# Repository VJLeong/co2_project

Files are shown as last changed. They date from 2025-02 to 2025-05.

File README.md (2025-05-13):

#  Automated Compensation of Environmental Changes on CO2 Gas Sensor Response
Project Supervisor: Dr. Ajay Achath Mohanan <br>
Project Members: Leong Van Jun, Vincent Law Yun Kae <br>
Project Commence Date: November 2024 - Present <br>
## Project Description <br>
The main objective of the project is to introduce Artificial Intelligence (AI) and/or machine learning (ML) tools to assist in analysing patterns in obtained carbon dioxide sensor readings and filtering of unwanted noises. <br>
This objective is achieved through proper setting up of the hardware setup and environment of the carbon dioxide sensor. Which is achieved by constructing of appropriate PCB and testing through external microcontroller units. <br>
For this project, the microcontroller unit used is the PSoC 5LP module and PCB design software used is Kicad 8.

## Changelog
### 13/5/2025:
  - Redesigned second version of external chamber PCB --  ready for remanufacturing if needed
  - Updated PID controller for heater controls to P controller (Kp = 120.0f)
### 18/4/2025:
  - Added external chamber PCB schematic design into the repo
  - Begin testing with external chamber PCB prototype
### 23/3/2025:
  - Updated capacitance.py to remove KNN cluster and median filtering algorithm to display raw data output in graph
  - Added heater PID bang-bang control and temperature sensor (3/3 tasks)
### 3/3/2025:
  - Written Python script involving KNN machine learning algorithm to help effeciently filter outlier values in read capacitance values
### 22/2/2025:
  - Re-updated read_capacitance function
  - Included improved analogue circuitry to measure capacitance, now using an
    NE556N timer module instead of simple RC circuit (LTSpice file included!)
### 13/2/2025:
  - Completed two tasks of three: Measure capacitance via PSoC
  - Currently debugging capacitance value, current capacitance value too small!
### 12/2/2025: 
  - Uploaded PSoC Creator and Kicad project files into Github repo for the first time.
  - Completed one task of three: Interface SCD30 on PCB with PSoC 5LP to obtain CO2 concentration, temperature, and relative humidity levels (rh%)

## Reference Materials
SCD30 item website: https://sensirion.com/products/catalog/SCD30 <br>
SCD30 Datasheet: https://sensirion.com/media/documents/4EAF6AF8/61652C3C/Sensirion_CO2_Sensors_SCD30_Datasheet.pdf <br>
SCD30 Interface Description: https://sensirion.com/media/documents/D7CEEF4A/6165372F/Sensirion_CO2_Sensors_SCD30_Interface_Description.pdf <br>
SCD30 Example Code: https://github.com/Sensirion/embedded-scd/releases/tag/2.1.1 <br>

## Acknowledgement
Thank you to Dr. Ajay for his supervision and guidance for the project members throughout the project duration.

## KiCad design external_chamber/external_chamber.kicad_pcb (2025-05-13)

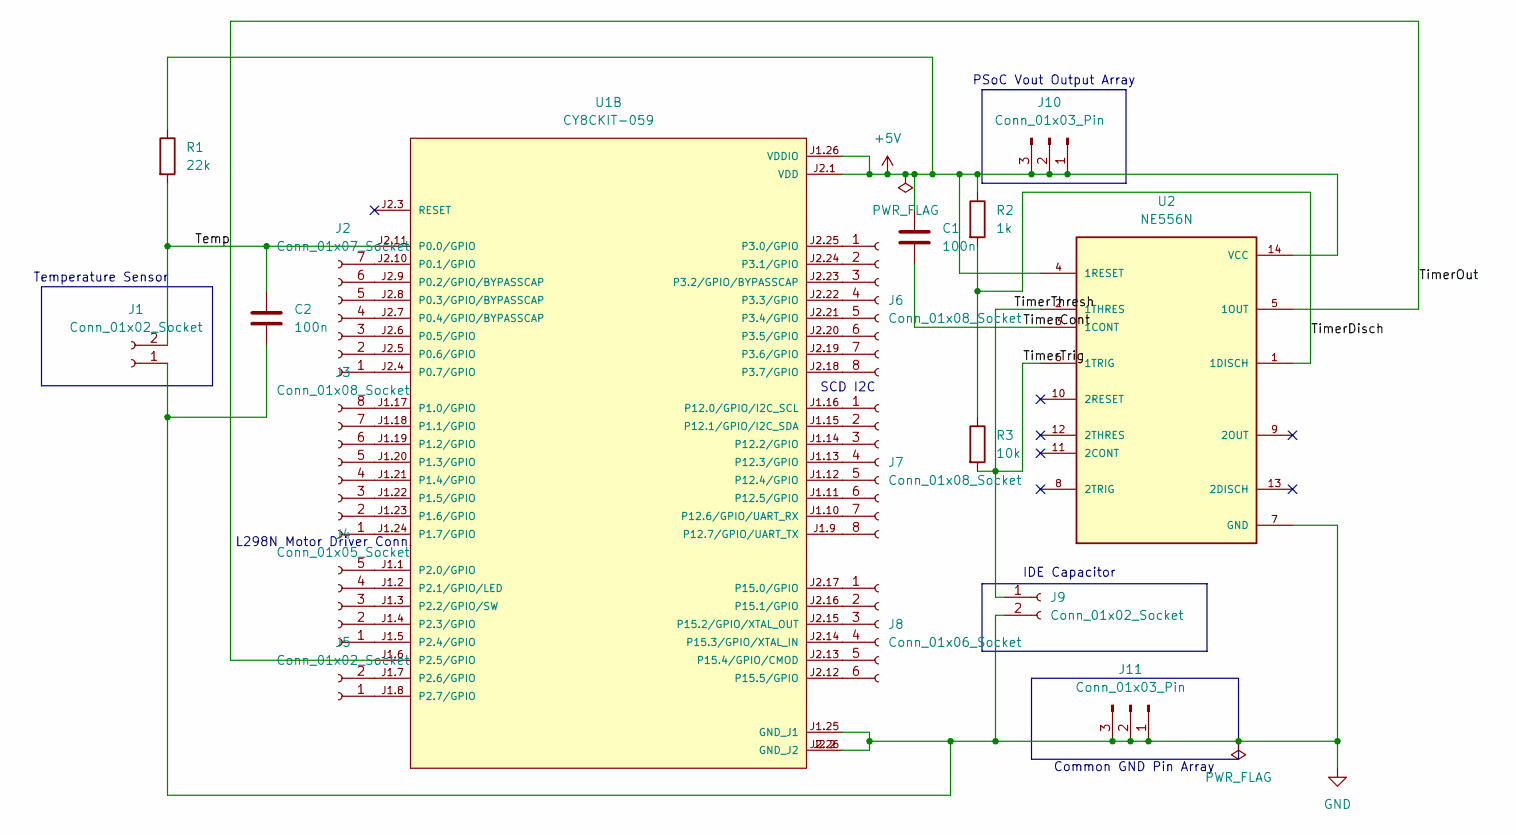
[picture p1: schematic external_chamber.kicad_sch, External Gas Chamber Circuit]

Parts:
C1, C2: 100n; C_Disc_D5.0mm_W2.5mm_P5.00mm
J1: Conn_01x02_Socket; PinHeader_1x02_P2.54mm_Vertical
J2: Conn_01x07_Socket; PinSocket_1x07_P2.54mm_Vertical
J3, J6: Conn_01x08_Socket; PinSocket_1x08_P2.54mm_Vertical
J4: Conn_01x05_Socket; PinSocket_1x05_P2.54mm_Vertical
J5, J9: Conn_01x02_Socket; PinSocket_1x02_P2.54mm_Vertical
J7: Conn_01x08_Socket; PinHeader_1x08_P2.54mm_Vertical
J8: Conn_01x06_Socket; PinSocket_1x06_P2.54mm_Vertical
J10, J11: Conn_01x03_Pin; PinSocket_1x03_P2.54mm_Vertical
R1: 22k; R_Axial_DIN0207_L6.3mm_D2.5mm_P7.62mm_Horizontal
R2: 1k; R_Axial_DIN0207_L6.3mm_D2.5mm_P7.62mm_Horizontal
R3: 10k; R_Axial_DIN0207_L6.3mm_D2.5mm_P7.62mm_Horizontal
U1: CY8CKIT-059; MODULE_CY8CKIT-059; PARTREV G
U2: NE556N; DIP794W45P254L1930H508Q14; PARTREV JUNE 2006; DigiKey_Part_Number 296-6504-5-ND

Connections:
+5V: C1.1, J10.1, J10.2, J10.3, R1.1, R2.1, U1.J1.26 (VDDIO), U1.J2.1 (VDD), U2.4 (1RESET), U2.14 (VCC)
/Temp: C2.1, J1.2, R1.2, U1.J2.11 (P0.0/GPIO)
/TimerCont: C1.2, U2.3 (1CONT)
/TimerDisch: R2.2, R3.1, U2.1 (1DISCH)
/TimerOut: U1.J1.6 (P2.5/GPIO), U2.5 (1OUT)
/TimerThresh: J9.1, R3.2, U2.2 (1THRES), U2.6 (1TRIG)
GND: C2.2, J1.1, J9.2, J11.1, J11.2, J11.3, U1.J1.25 (GND_J1), U1.J2.2 (GND_J2), U1.J2.26 (GND_J2), U2.7 (GND)
unnamed: J2.1, U1.J2.4 (P0.7/GPIO)
unnamed: J2.2, U1.J2.5 (P0.6/GPIO)
unnamed: J2.3, U1.J2.6 (P0.5/GPIO)
unnamed: J2.4, U1.J2.7 (P0.4/GPIO/BYPASSCAP)
unnamed: J2.5, U1.J2.8 (P0.3/GPIO/BYPASSCAP)
unnamed: J2.6, U1.J2.9 (P0.2/GPIO/BYPASSCAP)
unnamed: J2.7, U1.J2.10 (P0.1/GPIO)
unnamed: J3.1, U1.J1.24 (P1.7/GPIO)
unnamed: J3.2, U1.J1.23 (P1.6/GPIO)
unnamed: J3.3, U1.J1.22 (P1.5/GPIO)
unnamed: J3.4, U1.J1.21 (P1.4/GPIO)
unnamed: J3.5, U1.J1.20 (P1.3/GPIO)
unnamed: J3.6, U1.J1.19 (P1.2/GPIO)
unnamed: J3.7, U1.J1.18 (P1.1/GPIO)
unnamed: J3.8, U1.J1.17 (P1.0/GPIO)
unnamed: J4.1, U1.J1.5 (P2.4/GPIO)
unnamed: J4.2, U1.J1.4 (P2.3/GPIO)
unnamed: J4.3, U1.J1.3 (P2.2/GPIO/SW)
unnamed: J4.4, U1.J1.2 (P2.1/GPIO/LED)
unnamed: J4.5, U1.J1.1 (P2.0/GPIO)
unnamed: J5.1, U1.J1.8 (P2.7/GPIO)
unnamed: J5.2, U1.J1.7 (P2.6/GPIO)
unnamed: J6.1, U1.J2.25 (P3.0/GPIO)
unnamed: J6.2, U1.J2.24 (P3.1/GPIO)
unnamed: J6.3, U1.J2.23 (P3.2/GPIO/BYPASSCAP)
unnamed: J6.4, U1.J2.22 (P3.3/GPIO)
unnamed: J6.5, U1.J2.21 (P3.4/GPIO)
unnamed: J6.6, U1.J2.20 (P3.5/GPIO)
unnamed: J6.7, U1.J2.19 (P3.6/GPIO)
unnamed: J6.8, U1.J2.18 (P3.7/GPIO)
unnamed: J7.1, U1.J1.16 (P12.0/GPIO/I2C_SCL)
unnamed: J7.2, U1.J1.15 (P12.1/GPIO/I2C_SDA)
unnamed: J7.3, U1.J1.14 (P12.2/GPIO)
unnamed: J7.4, U1.J1.13 (P12.3/GPIO)
unnamed: J7.5, U1.J1.12 (P12.4/GPIO)
unnamed: J7.6, U1.J1.11 (P12.5/GPIO)
unnamed: J7.7, U1.J1.10 (P12.6/GPIO/UART_RX)
unnamed: J7.8, U1.J1.9 (P12.7/GPIO/UART_TX)
unnamed: J8.1, U1.J2.17 (P15.0/GPIO)
unnamed: J8.2, U1.J2.16 (P15.1/GPIO)
unnamed: J8.3, U1.J2.15 (P15.2/GPIO/XTAL_OUT)
unnamed: J8.4, U1.J2.14 (P15.3/GPIO/XTAL_IN)
unnamed: J8.5, U1.J2.13 (P15.4/GPIO/CMOD)
unnamed: J8.6, U1.J2.12 (P15.5/GPIO)

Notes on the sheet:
SCD I2C
IDE Capacitor
PSoC Vout Output Array
Common GND Pin Array
Temperature Sensor
L298N Motor Driver Conn.

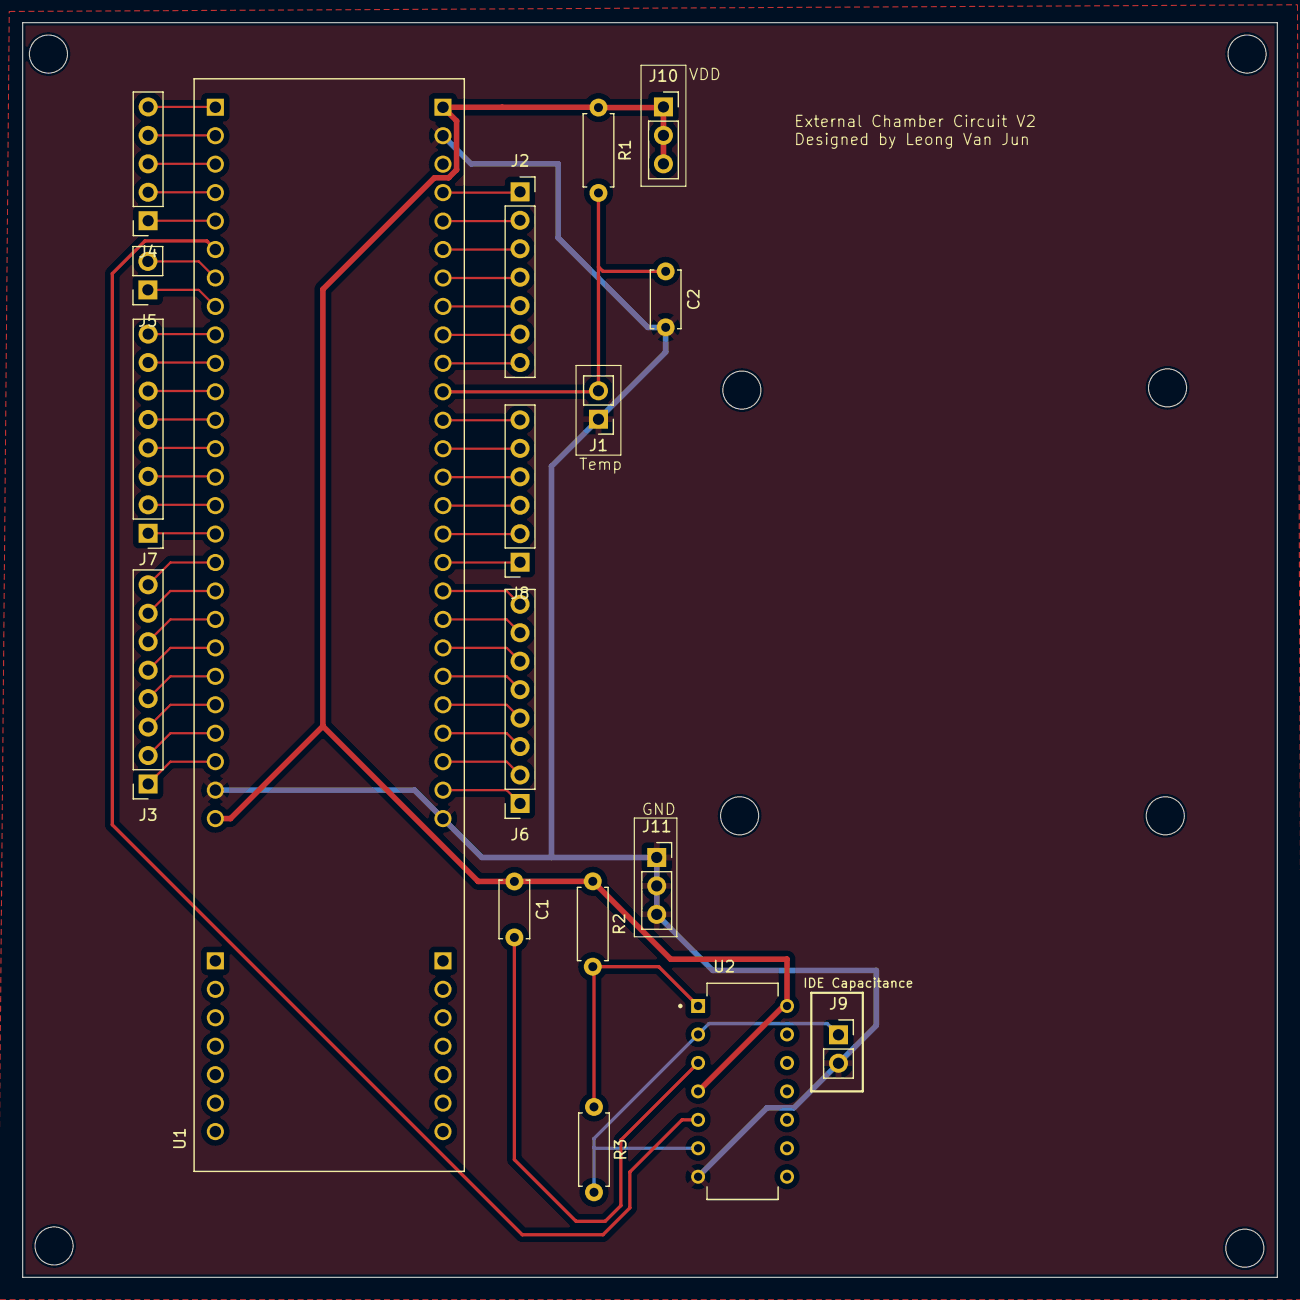
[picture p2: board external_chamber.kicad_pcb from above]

Board: 2 copper layers, 112.0 x 112.0 mm, 18 parts (0 on the bottom side), 51 nets.

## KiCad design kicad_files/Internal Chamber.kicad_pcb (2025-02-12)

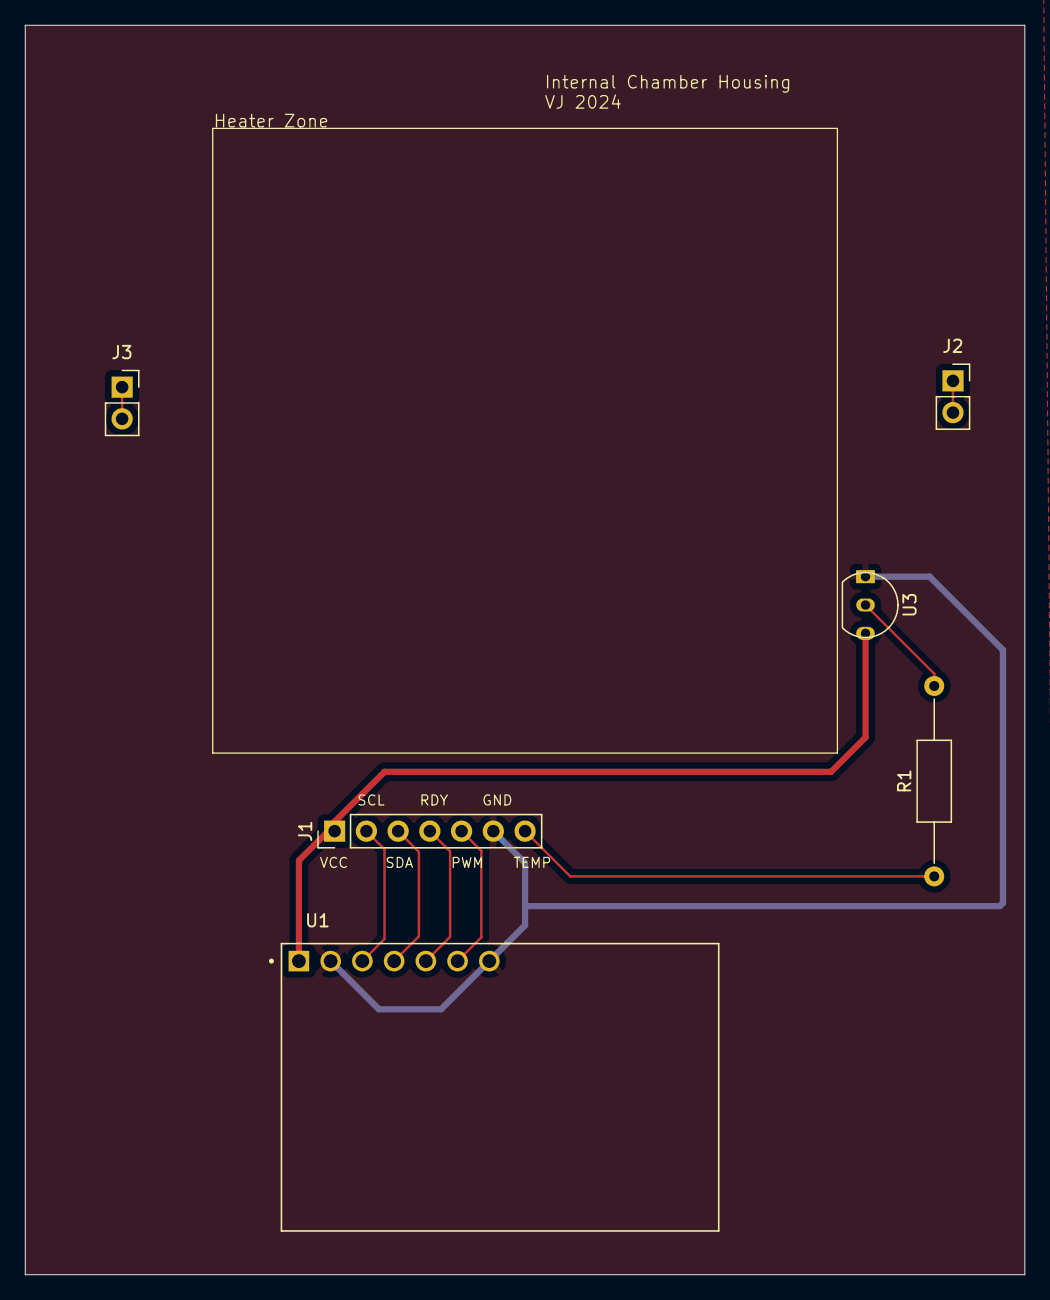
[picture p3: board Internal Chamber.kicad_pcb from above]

Board: 2 copper layers, 80.0 x 100.0 mm, 6 parts (0 on the bottom side), 9 nets.

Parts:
J1: Conn_01x07_Pin; PinHeader_1x07_P2.54mm_Vertical
J2, J3: Conn_01x02_Pin; PinSocket_1x02_P2.54mm_Vertical
R1: 4.7k; R_Axial_DIN0207_L6.3mm_D2.5mm_P15.24mm_Horizontal
U1: SCD30; MODULE_SCD30
U3: DS18B20; TO-92_Inline

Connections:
/Data: J2.1, J2.2, J3.1, J3.2
/PWM: J1.5, U1.6 (PWM)
/RDY: J1.4, U1.5 (RDY)
/SCL: J1.2, U1.3 (TX/SCL)
/SDA: J1.3, U1.4 (RX/SDA)
/TEMP: J1.7, R1.1
/VCC: J1.1, U1.1 (VDD), U3.3 (V_{DD})
GND: J1.6, U1.2 (GND), U1.7 (SEL), U3.1 (GND)
unnamed: R1.2, U3.2 (DQ)

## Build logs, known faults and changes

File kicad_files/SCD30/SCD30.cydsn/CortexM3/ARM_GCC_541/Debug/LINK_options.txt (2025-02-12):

-Wl,--start-group -o "F:\\Downloads\\kicad\\sandbox\\Internal\ Chamber\\SCD30\\SCD30.cydsn\\CortexM3\\ARM_GCC_541\\Debug\\SCD30.elf" ".\\CortexM3\\ARM_GCC_541\\Debug\\main.o" ".\\CortexM3\\ARM_GCC_541\\Debug\\cyfitter_cfg.o" ".\\CortexM3\\ARM_GCC_541\\Debug\\cymetadata.o" ".\\CortexM3\\ARM_GCC_541\\Debug\\Cm3Start.o" ".\\CortexM3\\ARM_GCC_541\\Debug\\SCD30.a" "F:\\PSoC\ Creator\\4.4\\PSoC\ Creator\\psoc\\content\\cycomponentlibrary\\CyComponentLibrary.cylib\\CortexM3\\ARM_GCC_541\\Debug\\CyComponentLibrary.a" -mcpu=cortex-m3 -mthumb -L "Generated_Source\\PSoC5" "-Wl,-Map,.\\CortexM3\\ARM_GCC_541\\Debug/SCD30.map" -T "Generated_Source\\PSoC5\\cm3gcc.ld" -specs=nano.specs -Wl,--gc-sections -u_printf_float -g -ffunction-sections -Og -ffat-lto-objects -Wl,--end-group

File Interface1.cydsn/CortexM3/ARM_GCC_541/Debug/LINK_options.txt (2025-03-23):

-Wl,--start-group -o "F:\\Downloads\\SLED\\Workspace01\\Interface1.cydsn\\CortexM3\\ARM_GCC_541\\Debug\\Interface1.elf" ".\\CortexM3\\ARM_GCC_541\\Debug\\main.o" ".\\CortexM3\\ARM_GCC_541\\Debug\\cyfitter_cfg.o" ".\\CortexM3\\ARM_GCC_541\\Debug\\cymetadata.o" ".\\CortexM3\\ARM_GCC_541\\Debug\\Cm3Start.o" ".\\CortexM3\\ARM_GCC_541\\Debug\\Interface1.a" "F:\\PSoC\ Creator\\4.4\\PSoC\ Creator\\psoc\\content\\cycomponentlibrary\\CyComponentLibrary.cylib\\CortexM3\\ARM_GCC_541\\Debug\\CyComponentLibrary.a" -mcpu=cortex-m3 -mthumb -l m -L "Generated_Source\\PSoC5" "-Wl,-Map,.\\CortexM3\\ARM_GCC_541\\Debug/Interface1.map" -T "Generated_Source\\PSoC5\\cm3gcc.ld" -u _printf_float -Wl,--gc-sections -u_printf_float -g -ffunction-sections -Og -ffat-lto-objects -Wl,--end-group

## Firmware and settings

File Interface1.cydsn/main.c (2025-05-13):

#include "project.h"
#include <stdlib.h>
#include <stdio.h>
#include <math.h>

// Definitions
#define SCD30_I2C_ADDRESS 0x61
#define R1 1000.0 // 1k ohm resistor
#define R2 10000.0 // 10k ohm resistor
#define R3 22000.0 //22k ohm resistor
#define VREF 4.9
#define ADC_MAX_VALUE 4095
// JS6670 nominal parameters (from datasheet/specs)
#define R0          9983.0      // Nominal resistance at 25°C in Ohms
#define T0          298.15      // Nominal temperature in Kelvin (25°C)
#define BETA        3870.0     // Beta parameter in Kelvin

// Function prototypes
void I2C_Write(uint8_t *data, uint8_t length);
void I2C_Read(uint8_t *data, uint8_t length);
void read_sensor_data();
void read_capacitance();
void heater();
void read_temperature();
// Global variables
char string_1[100];
uint8_t buffer[18]; // Buffer for 18 bytes of data
uint16 adcResult;
int heaterDutyCycle;
uint8 status;
float  voltage;
float  R_thermistor;
float  temperatureK, temperatureC;
int    tempCeil;
// Temperature control (PID)
float Kp = 120.0f;
float Ki = 0.0f;
float Kd = 0.0f;
float dt = 0.001f; // Sampling every 1ms
float setpoint = 60.0f;
float error, derivative, integral, prevErr;

void I2C_Write(uint8_t *data, uint8_t length) {
    I2C_1_MasterWriteBuf(SCD30_I2C_ADDRESS, data, length, I2C_1_MODE_COMPLETE_XFER);
    while(I2C_1_MasterStatus() & I2C_1_MSTAT_XFER_INP);
}

void I2C_Read(uint8_t *data, uint8_t length) {
    I2C_1_MasterReadBuf(SCD30_I2C_ADDRESS, data, length, I2C_1_MODE_COMPLETE_XFER);
    while(I2C_1_MasterStatus() & I2C_1_MSTAT_XFER_INP);
}

void read_sensor_data()
{
    // Ensure buffer is updated before reading values
    I2C_Read(buffer, sizeof(buffer));  

    uint32_t co2BytesUpper = (buffer[0] << 8) | buffer[1];
    uint32_t co2BytesLower = (buffer[3] << 8) | buffer[4];
    uint32_t co2Bytes = ((uint32_t)co2BytesUpper << 16) | co2BytesLower;
    int co2Concentration = (int)*(float*)&co2Bytes;
    
    uint32_t tempBytesUpper = (buffer[6] << 8) | buffer[7];
    uint32_t tempBytesLower = (buffer[9] << 8) | buffer[10];
    uint32_t tempBytes = ((uint32_t)tempBytesUpper << 16) | tempBytesLower;
    int temperature = (int)*(float*)&tempBytes;
    
    uint32_t rhBytesUpper = (buffer[12] << 8) | buffer[13];
    uint32_t rhBytesLower = (buffer[15] << 8) | buffer[16];
    uint32_t rhBytes = ((uint32_t)rhBytesUpper << 16) | rhBytesLower;
    int rh = (int)*(float*)&rhBytes;
    
//    float capacitance = read_capacitance();
    
    if (co2Concentration != 0 && temperature != 0 && rh != 0)
    {
        sprintf(string_1, "CO2: %d ppm, Temperature: %d degrees, Relative Humidity: %d%%\n", co2Concentration, temperature, rh);
        UART_1_PutString(string_1);  // Send output via UART
    }
}

void read_capacitance()
{
    // 1) Clear the counter
    Counter_1_WriteCounter(0);  
    
    // 2) Wait a known time (e.g., 1 second)
    CyDelay(1000);  // 1000 ms
    
    // 3) Read how many pulses arrived in that time
    uint32_t pulseCount = Counter_1_ReadCounter();
    // Calculate the capacitance connected
    double capMeasured = 1.44/((R1 + 2*R2)*pulseCount) * 1.0e9;
    // 4) That count is your frequency in Hz (since you waited 1 second)
    sprintf(string_1,"Frequency = %lu Hz, Capacitance: %.2f nF\n", (unsigned long)pulseCount, capMeasured);
    UART_1_PutString(string_1);
}

// Bang-bang on/off controller test implementation
void heater()
{
    // Start the PWM module once
    PWM_1_Start();
    // Set the heater direction: only one side is activated for heat flow.
    Heater_IN1_Write(1);
    Heater_IN2_Write(0);
    
    // Set the duty cycle to 100% (for full power)
    heaterDutyCycle = 255;
    PWM_1_WriteCompare(heaterDutyCycle);
    
    // Enable the heater channel by setting the ENA pin high.
    Heater_ENA_Write(1);
    UART_1_PutString("Begin heating...\n");
    
    // Loop until the temperature exceeds 60°C
    // May need extra condition such that when capacitance of IDE goes down below threshold, heater stops
    while (tempCeil <= setpoint) // 1 to keep heating
    {
        // Read temperature and update the global variable tempCeil
        read_temperature();
        
        error = setpoint - temperatureC;
        integral += error*dt;
        derivative = (error - prevErr)/dt;
        prevErr = error;
        
        float output = error*Kp + integral*Ki + derivative*Kd;
        heaterDutyCycle = (int)output;
        // Clamp pwm duty cycle
        if (heaterDutyCycle > 255)
        {
            heaterDutyCycle = 255;
        }
        else if (heaterDutyCycle < 0)
        {
            heaterDutyCycle = 0;
        }
        
                
        // Update PWM cycle
        PWM_1_WriteCompare(heaterDutyCycle);
        
        // Print out controls params
        sprintf(string_1, "Set: %.2f, Temp: %.2f, Err: %.2f, PWM: %d, Out: %.2f\r\n", setpoint, temperatureC, error, heaterDutyCycle, output);
        UART_1_PutString(string_1);
    }
    
    // Turn off the heater once 60°C is reached
    Heater_ENA_Write(0);
    PWM_1_Stop();
    
    // Set the control pins to low
    Heater_IN1_Write(0);
    Heater_IN2_Write(0);
    UART_1_PutString("Heating stopped.\n");
}


void read_temperature()
{
    
        /* Kick off a single ADC conversion */
        ADC_SAR_1_StartConvert();

        /* Wait until the conversion completes */
        do
        {
            status = ADC_SAR_1_IsEndConversion(ADC_SAR_1_RETURN_STATUS);
        }
        while (status == 0);

        /* Get the ADC raw count */
        adcResult = ADC_SAR_1_GetResult16();

        /* Convert raw count to a voltage in [0..VREF] */
        voltage = ADC_SAR_1_CountsTo_Volts(adcResult);

        R_thermistor = R3*(VREF - voltage) / voltage;

        /* Compute temperature using Beta equation if R_thermistor > 0 */
        if (R_thermistor > 0.0f)
        {
            /* T(K) = BETA / (ln(R/R0) + (BETA/T0)) */
            temperatureK = BETA / (logf(R_thermistor / R0) + (BETA / T0));
            temperatureC = temperatureK - 273.15f;
        }
        else
        {
            temperatureC = -999.0f;  // sentinel for error
        }

//        /* Round up the temperature to next integer */
//        tempCeil = (int)ceilf(temperatureC);

        /* Print integer result via UART */
        sprintf(string_1, "Current temperature: %.2f degrees Celsius\r\n", temperatureC);
        UART_1_PutString(string_1);

        /* Delay 1 second before next reading */
        CyDelay(1000u);
}



int main(void) {
    CyGlobalIntEnable;
    I2C_1_Start();
    UART_1_Start();
    Counter_1_Start();
    //PWM_1_Start();
    ADC_SAR_1_Start();

    // Start continuous measurement with 0x0010 command and pressure 0x0000
    uint8_t startCmd[5] = {0x00, 0x10, 0x00, 0x00, 0x81}; // 0x81 is CRC for 0x0000
    I2C_Write(startCmd, sizeof(startCmd));
    CyDelay(1000); // Allow sensor initialization
    UART_1_PutString("Starting sensor reading...\n");
    heater();
    for(;;) 
    {
//        // Command to read data (0x0300)
//        uint8_t readCmd[2] = {0x03, 0x00};
//        I2C_Write(readCmd, sizeof(readCmd));
//        CyDelay(300); // Wait for command processing
//        read_sensor_data();
//        CyDelay(1000); // Match measurement interval
//        read_capacitance();
////        
//        // Temperature sensor
//        read_temperature();
    }
}

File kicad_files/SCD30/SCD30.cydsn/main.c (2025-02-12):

#include "project.h"
#include <string.h>
#include <stdio.h>

#define SCD30_I2C_ADDRESS 0x61  // Default SCD30 I2C address

uint8_t buffer[18];
char string_1[50] = "\0";

// Function to send a 16-bit command over I2C
void I2C_Write(uint16_t cmd) {
    uint8_t data[2] = { (uint8_t)(cmd >> 8), (uint8_t)(cmd & 0xFF) };
    I2C_1_MasterWriteBuf(SCD30_I2C_ADDRESS, data, 2, I2C_1_MODE_COMPLETE_XFER);
    while(I2C_1_MasterStatus() & I2C_1_MSTAT_XFER_INP);
}

// Function to check if the sensor has data ready
uint8_t I2C_ReadDataReady() {
    // The correct command for "read data ready" is 0x02 0x02
    uint8_t cmd[2] = {0x02, 0x02};
    uint8_t resp[3];

    I2C_1_MasterWriteBuf(SCD30_I2C_ADDRESS, cmd, 2, I2C_1_MODE_COMPLETE_XFER);
    while(I2C_1_MasterStatus() & I2C_1_MSTAT_XFER_INP);

    I2C_1_MasterReadBuf(SCD30_I2C_ADDRESS, resp, 3, I2C_1_MODE_COMPLETE_XFER);
    while(I2C_1_MasterStatus() & I2C_1_MSTAT_XFER_INP);

    // The sensor returns a 16-bit value; here we simply check the second byte.
    return resp[1];  
}

// Function to read measurement data (18 bytes) from the sensor
void I2C_ReadMeasurements() {
    uint8_t cmd[2] = {0x03, 0x00};  // Read measurement command
    I2C_1_MasterWriteBuf(SCD30_I2C_ADDRESS, cmd, 2, I2C_1_MODE_COMPLETE_XFER);
    while(I2C_1_MasterStatus() & I2C_1_MSTAT_XFER_INP);

    I2C_1_MasterReadBuf(SCD30_I2C_ADDRESS, buffer, 18, I2C_1_MODE_COMPLETE_XFER);
    while(I2C_1_MasterStatus() & I2C_1_MSTAT_XFER_INP);
}

// Converts 5 bytes (2 data bytes, 1 CRC, then 2 data bytes) into a float
// Assumes that the CRC byte (at index 2) is skipped.
float bytes_to_float(uint8_t *bytes) {
    uint32_t raw = ((uint32_t)bytes[0] << 24) |
                   ((uint32_t)bytes[1] << 16) |
                   ((uint32_t)bytes[3] << 8)  |
                   ((uint32_t)bytes[4]);
    float value;
    memcpy(&value, &raw, sizeof(float));
    return value;
}

int main(void)
{
    CyGlobalIntEnable;  // Enable global interrupts
    I2C_1_Start();      // Start I2C component
    UART_1_Start();     // Start UART for debugging

    UART_1_PutString("Scanning I2C...\r\n");

    uint8_t status = I2C_1_MasterSendStart(SCD30_I2C_ADDRESS, I2C_1_WRITE_XFER_MODE);
    
    if(status == I2C_1_MSTR_NO_ERROR)
    {
        UART_1_PutString("SCD30 found at address 0x61!\r\n");
        I2C_1_MasterSendStop();
    }
    else
    {
        UART_1_PutString("No response from SCD30!\r\n");
    }
    
    // Start continuous measurement (0x0010). 
    // Optionally, you can send ambient pressure as a 16-bit value (set to 0 if not used).
    I2C_Write(0x0010);

    UART_1_PutString("Give the sensor some time to complete its first measurement\r\n");
    CyDelay(3000);
    UART_1_PutString("Ready to output values\r\n");
    
    for(;;)
    {
        // Check if new data is ready (returns non-zero when ready)
        if (I2C_ReadDataReady())
        {
            I2C_ReadMeasurements();

            // Each measurement is 5 bytes:
            // - CO2: indices 0-4 (skip index 2)
            // - Temperature: indices 6-10 (skip index 8)
            // - Humidity: indices 12-16 (skip index 14)
            float co2 = bytes_to_float(&buffer[0]);
            float temp = bytes_to_float(&buffer[6]);
            float humidity = bytes_to_float(&buffer[12]);

            sprintf(string_1, "CO2: %.2f ppm\r\n", co2);
            UART_1_PutString(string_1);
        }
        CyDelay(2000);  // Wait 2 seconds before next check
    }
}

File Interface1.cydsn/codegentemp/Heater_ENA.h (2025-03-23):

/*******************************************************************************
* File Name: Heater_ENA.h  
* Version 2.20
*
* Description:
*  This file contains Pin function prototypes and register defines
*
* Note:
*
********************************************************************************
* Copyright 2008-2015, Cypress Semiconductor Corporation.  All rights reserved.
* You may use this file only in accordance with the license, terms, conditions, 
* disclaimers, and limitations in the end user license agreement accompanying 
* the software package with which this file was provided.
*******************************************************************************/

#if !defined(CY_PINS_Heater_ENA_H) /* Pins Heater_ENA_H */
#define CY_PINS_Heater_ENA_H

#include "cytypes.h"
#include "cyfitter.h"
#include "cypins.h"
#include "Heater_ENA_aliases.h"

/* APIs are not generated for P15[7:6] */
#if !(CY_PSOC5A &&\
	 Heater_ENA__PORT == 15 && ((Heater_ENA__MASK & 0xC0) != 0))


/***************************************
*        Function Prototypes             
***************************************/    

/**
* \addtogroup group_general
* @{
*/
void    Heater_ENA_Write(uint8 value);
void    Heater_ENA_SetDriveMode(uint8 mode);
uint8   Heater_ENA_ReadDataReg(void);
uint8   Heater_ENA_Read(void);
void    Heater_ENA_SetInterruptMode(uint16 position, uint16 mode);
uint8   Heater_ENA_ClearInterrupt(void);
/** @} general */

/***************************************
*           API Constants        
***************************************/
/**
* \addtogroup group_constants
* @{
*/
    /** \addtogroup driveMode Drive mode constants
     * \brief Constants to be passed as "mode" parameter in the Heater_ENA_SetDriveMode() function.
     *  @{
     */
        #define Heater_ENA_DM_ALG_HIZ         PIN_DM_ALG_HIZ
        #define Heater_ENA_DM_DIG_HIZ         PIN_DM_DIG_HIZ
        #define Heater_ENA_DM_RES_UP          PIN_DM_RES_UP
        #define Heater_ENA_DM_RES_DWN         PIN_DM_RES_DWN
        #define Heater_ENA_DM_OD_LO           PIN_DM_OD_LO
        #define Heater_ENA_DM_OD_HI           PIN_DM_OD_HI
        #define Heater_ENA_DM_STRONG          PIN_DM_STRONG
        #define Heater_ENA_DM_RES_UPDWN       PIN_DM_RES_UPDWN
    /** @} driveMode */
/** @} group_constants */
    
/* Digital Port Constants */
#define Heater_ENA_MASK               Heater_ENA__MASK
#define Heater_ENA_SHIFT              Heater_ENA__SHIFT
#define Heater_ENA_WIDTH              1u

/* Interrupt constants */
#if defined(Heater_ENA__INTSTAT)
/**
* \addtogroup group_constants
* @{
*/
    /** \addtogroup intrMode Interrupt constants
     * \brief Constants to be passed as "mode" parameter in Heater_ENA_SetInterruptMode() function.
     *  @{
     */
        #define Heater_ENA_INTR_NONE      (uint16)(0x0000u)
        #define Heater_ENA_INTR_RISING    (uint16)(0x0001u)
        #define Heater_ENA_INTR_FALLING   (uint16)(0x0002u)
        #define Heater_ENA_INTR_BOTH      (uint16)(0x0003u) 
    /** @} intrMode */
/** @} group_constants */

    #define Heater_ENA_INTR_MASK      (0x01u) 
#endif /* (Heater_ENA__INTSTAT) */


/***************************************
*             Registers        
***************************************/

/* Main Port Registers */
/* Pin State */
#define Heater_ENA_PS                     (* (reg8 *) Heater_ENA__PS)
/* Data Register */
#define Heater_ENA_DR                     (* (reg8 *) Heater_ENA__DR)
/* Port Number */
#define Heater_ENA_PRT_NUM                (* (reg8 *) Heater_ENA__PRT) 
/* Connect to Analog Globals */                                                  
#define Heater_ENA_AG                     (* (reg8 *) Heater_ENA__AG)                       
/* Analog MUX bux enable */
#define Heater_ENA_AMUX                   (* (reg8 *) Heater_ENA__AMUX) 
/* Bidirectional Enable */                                                        
#define Heater_ENA_BIE                    (* (reg8 *) Heater_ENA__BIE)
/* Bit-mask for Aliased Register Access */
#define Heater_ENA_BIT_MASK               (* (reg8 *) Heater_ENA__BIT_MASK)
/* Bypass Enable */
#define Heater_ENA_BYP                    (* (reg8 *) Heater_ENA__BYP)
/* Port wide control signals */                                                   
#define Heater_ENA_CTL                    (* (reg8 *) Heater_ENA__CTL)
/* Drive Modes */
#define Heater_ENA_DM0                    (* (reg8 *) Heater_ENA__DM0) 
#define Heater_ENA_DM1                    (* (reg8 *) Heater_ENA__DM1)
#define Heater_ENA_DM2                    (* (reg8 *) Heater_ENA__DM2) 
/* Input Buffer Disable Override */
#define Heater_ENA_INP_DIS                (* (reg8 *) Heater_ENA__INP_DIS)
/* LCD Common or Segment Drive */
#define Heater_ENA_LCD_COM_SEG            (* (reg8 *) Heater_ENA__LCD_COM_SEG)
/* Enable Segment LCD */
#define Heater_ENA_LCD_EN                 (* (reg8 *) Heater_ENA__LCD_EN)
/* Slew Rate Control */
#define Heater_ENA_SLW                    (* (reg8 *) Heater_ENA__SLW)

/* DSI Port Registers */
/* Global DSI Select Register */
#define Heater_ENA_PRTDSI__CAPS_SEL       (* (reg8 *) Heater_ENA__PRTDSI__CAPS_SEL) 
/* Double Sync Enable */
#define Heater_ENA_PRTDSI__DBL_SYNC_IN    (* (reg8 *) Heater_ENA__PRTDSI__DBL_SYNC_IN) 
/* Output Enable Select Drive Strength */
#define Heater_ENA_PRTDSI__OE_SEL0        (* (reg8 *) Heater_ENA__PRTDSI__OE_SEL0) 
#define Heater_ENA_PRTDSI__OE_SEL1        (* (reg8 *) Heater_ENA__PRTDSI__OE_SEL1) 
/* Port Pin Output Select Registers */
#define Heater_ENA_PRTDSI__OUT_SEL0       (* (reg8 *) Heater_ENA__PRTDSI__OUT_SEL0) 
#define Heater_ENA_PRTDSI__OUT_SEL1       (* (reg8 *) Heater_ENA__PRTDSI__OUT_SEL1) 
/* Sync Output Enable Registers */
#define Heater_ENA_PRTDSI__SYNC_OUT       (* (reg8 *) Heater_ENA__PRTDSI__SYNC_OUT) 

/* SIO registers */
#if defined(Heater_ENA__SIO_CFG)
    #define Heater_ENA_SIO_HYST_EN        (* (reg8 *) Heater_ENA__SIO_HYST_EN)
    #define Heater_ENA_SIO_REG_HIFREQ     (* (reg8 *) Heater_ENA__SIO_REG_HIFREQ)
    #define Heater_ENA_SIO_CFG            (* (reg8 *) Heater_ENA__SIO_CFG)
    #define Heater_ENA_SIO_DIFF           (* (reg8 *) Heater_ENA__SIO_DIFF)
#endif /* (Heater_ENA__SIO_CFG) */

/* Interrupt Registers */
#if defined(Heater_ENA__INTSTAT)
    #define Heater_ENA_INTSTAT            (* (reg8 *) Heater_ENA__INTSTAT)
    #define Heater_ENA_SNAP               (* (reg8 *) Heater_ENA__SNAP)
    
	#define Heater_ENA_0_INTTYPE_REG 		(* (reg8 *) Heater_ENA__0__INTTYPE)
#endif /* (Heater_ENA__INTSTAT) */

#endif /* CY_PSOC5A... */

#endif /*  CY_PINS_Heater_ENA_H */


/* [] END OF FILE */

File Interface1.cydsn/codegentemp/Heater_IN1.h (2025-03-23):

/*******************************************************************************
* File Name: Heater_IN1.h  
* Version 2.20
*
* Description:
*  This file contains Pin function prototypes and register defines
*
* Note:
*
********************************************************************************
* Copyright 2008-2015, Cypress Semiconductor Corporation.  All rights reserved.
* You may use this file only in accordance with the license, terms, conditions, 
* disclaimers, and limitations in the end user license agreement accompanying 
* the software package with which this file was provided.
*******************************************************************************/

#if !defined(CY_PINS_Heater_IN1_H) /* Pins Heater_IN1_H */
#define CY_PINS_Heater_IN1_H

#include "cytypes.h"
#include "cyfitter.h"
#include "cypins.h"
#include "Heater_IN1_aliases.h"

/* APIs are not generated for P15[7:6] */
#if !(CY_PSOC5A &&\
	 Heater_IN1__PORT == 15 && ((Heater_IN1__MASK & 0xC0) != 0))


/***************************************
*        Function Prototypes             
***************************************/    

/**
* \addtogroup group_general
* @{
*/
void    Heater_IN1_Write(uint8 value);
void    Heater_IN1_SetDriveMode(uint8 mode);
uint8   Heater_IN1_ReadDataReg(void);
uint8   Heater_IN1_Read(void);
void    Heater_IN1_SetInterruptMode(uint16 position, uint16 mode);
uint8   Heater_IN1_ClearInterrupt(void);
/** @} general */

/***************************************
*           API Constants        
***************************************/
/**
* \addtogroup group_constants
* @{
*/
    /** \addtogroup driveMode Drive mode constants
     * \brief Constants to be passed as "mode" parameter in the Heater_IN1_SetDriveMode() function.
     *  @{
     */
        #define Heater_IN1_DM_ALG_HIZ         PIN_DM_ALG_HIZ
        #define Heater_IN1_DM_DIG_HIZ         PIN_DM_DIG_HIZ
        #define Heater_IN1_DM_RES_UP          PIN_DM_RES_UP
        #define Heater_IN1_DM_RES_DWN         PIN_DM_RES_DWN
        #define Heater_IN1_DM_OD_LO           PIN_DM_OD_LO
        #define Heater_IN1_DM_OD_HI           PIN_DM_OD_HI
        #define Heater_IN1_DM_STRONG          PIN_DM_STRONG
        #define Heater_IN1_DM_RES_UPDWN       PIN_DM_RES_UPDWN
    /** @} driveMode */
/** @} group_constants */
    
/* Digital Port Constants */
#define Heater_IN1_MASK               Heater_IN1__MASK
#define Heater_IN1_SHIFT              Heater_IN1__SHIFT
#define Heater_IN1_WIDTH              1u

/* Interrupt constants */
#if defined(Heater_IN1__INTSTAT)
/**
* \addtogroup group_constants
* @{
*/
    /** \addtogroup intrMode Interrupt constants
     * \brief Constants to be passed as "mode" parameter in Heater_IN1_SetInterruptMode() function.
     *  @{
     */
        #define Heater_IN1_INTR_NONE      (uint16)(0x0000u)
        #define Heater_IN1_INTR_RISING    (uint16)(0x0001u)
        #define Heater_IN1_INTR_FALLING   (uint16)(0x0002u)
        #define Heater_IN1_INTR_BOTH      (uint16)(0x0003u) 
    /** @} intrMode */
/** @} group_constants */

    #define Heater_IN1_INTR_MASK      (0x01u) 
#endif /* (Heater_IN1__INTSTAT) */


/***************************************
*             Registers        
***************************************/

/* Main Port Registers */
/* Pin State */
#define Heater_IN1_PS                     (* (reg8 *) Heater_IN1__PS)
/* Data Register */
#define Heater_IN1_DR                     (* (reg8 *) Heater_IN1__DR)
/* Port Number */
#define Heater_IN1_PRT_NUM                (* (reg8 *) Heater_IN1__PRT) 
/* Connect to Analog Globals */                                                  
#define Heater_IN1_AG                     (* (reg8 *) Heater_IN1__AG)                       
/* Analog MUX bux enable */
#define Heater_IN1_AMUX                   (* (reg8 *) Heater_IN1__AMUX) 
/* Bidirectional Enable */                                                        
#define Heater_IN1_BIE                    (* (reg8 *) Heater_IN1__BIE)
/* Bit-mask for Aliased Register Access */
#define Heater_IN1_BIT_MASK               (* (reg8 *) Heater_IN1__BIT_MASK)
/* Bypass Enable */
#define Heater_IN1_BYP                    (* (reg8 *) Heater_IN1__BYP)
/* Port wide control signals */                                                   
#define Heater_IN1_CTL                    (* (reg8 *) Heater_IN1__CTL)
/* Drive Modes */
#define Heater_IN1_DM0                    (* (reg8 *) Heater_IN1__DM0) 
#define Heater_IN1_DM1                    (* (reg8 *) Heater_IN1__DM1)
#define Heater_IN1_DM2                    (* (reg8 *) Heater_IN1__DM2) 
/* Input Buffer Disable Override */
#define Heater_IN1_INP_DIS                (* (reg8 *) Heater_IN1__INP_DIS)
/* LCD Common or Segment Drive */
#define Heater_IN1_LCD_COM_SEG            (* (reg8 *) Heater_IN1__LCD_COM_SEG)
/* Enable Segment LCD */
#define Heater_IN1_LCD_EN                 (* (reg8 *) Heater_IN1__LCD_EN)
/* Slew Rate Control */
#define Heater_IN1_SLW                    (* (reg8 *) Heater_IN1__SLW)

/* DSI Port Registers */
/* Global DSI Select Register */
#define Heater_IN1_PRTDSI__CAPS_SEL       (* (reg8 *) Heater_IN1__PRTDSI__CAPS_SEL) 
/* Double Sync Enable */
#define Heater_IN1_PRTDSI__DBL_SYNC_IN    (* (reg8 *) Heater_IN1__PRTDSI__DBL_SYNC_IN) 
/* Output Enable Select Drive Strength */
#define Heater_IN1_PRTDSI__OE_SEL0        (* (reg8 *) Heater_IN1__PRTDSI__OE_SEL0) 
#define Heater_IN1_PRTDSI__OE_SEL1        (* (reg8 *) Heater_IN1__PRTDSI__OE_SEL1) 
/* Port Pin Output Select Registers */
#define Heater_IN1_PRTDSI__OUT_SEL0       (* (reg8 *) Heater_IN1__PRTDSI__OUT_SEL0) 
#define Heater_IN1_PRTDSI__OUT_SEL1       (* (reg8 *) Heater_IN1__PRTDSI__OUT_SEL1) 
/* Sync Output Enable Registers */
#define Heater_IN1_PRTDSI__SYNC_OUT       (* (reg8 *) Heater_IN1__PRTDSI__SYNC_OUT) 

/* SIO registers */
#if defined(Heater_IN1__SIO_CFG)
    #define Heater_IN1_SIO_HYST_EN        (* (reg8 *) Heater_IN1__SIO_HYST_EN)
    #define Heater_IN1_SIO_REG_HIFREQ     (* (reg8 *) Heater_IN1__SIO_REG_HIFREQ)
    #define Heater_IN1_SIO_CFG            (* (reg8 *) Heater_IN1__SIO_CFG)
    #define Heater_IN1_SIO_DIFF           (* (reg8 *) Heater_IN1__SIO_DIFF)
#endif /* (Heater_IN1__SIO_CFG) */

/* Interrupt Registers */
#if defined(Heater_IN1__INTSTAT)
    #define Heater_IN1_INTSTAT            (* (reg8 *) Heater_IN1__INTSTAT)
    #define Heater_IN1_SNAP               (* (reg8 *) Heater_IN1__SNAP)
    
	#define Heater_IN1_0_INTTYPE_REG 		(* (reg8 *) Heater_IN1__0__INTTYPE)
#endif /* (Heater_IN1__INTSTAT) */

#endif /* CY_PSOC5A... */

#endif /*  CY_PINS_Heater_IN1_H */


/* [] END OF FILE */

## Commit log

2025-02-12 First commit into GitHub!
    [Interface1.sdf]
2025-02-12 Added Kicad Files for reference and updated .gitignore file
    [Internal Chamber-B_Cu.gbr, Internal Chamber-B_Mask.gbr, Internal Chamber-B_Paste.gbr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]
2025-02-13 Added capacitance measurement, debugging required
    [Interface1.sdf]
2025-02-22 Updated capacitance measurement capability and added LTSpice circuit diagram of updated capacitance measuring circuit
    [Interface1.sdf]
2025-03-03 Added capacitor.py to track and filter capacitance values
2025-03-03 Updated capacitance.py to output final measured output
    [Interface1.sdf]
2025-03-23 Added heater controls and temperature sensing
    [Interface1.sdf]
2025-03-23 Updated temperature sensing sensitivity, getting ready to turn into RTOS
2025-03-23 Further updates for heater controls
2025-04-18 Added external chamber PCB design files and schematic diagram
    [external_chamber-B_Cu.gbr, external_chamber-B_Mask.gbr, external_chamber-B_Paste.gbr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]
2025-05-13 Updated heater controls and uploaded re-design of external chamber PCB
    [Interface1.sdf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]
